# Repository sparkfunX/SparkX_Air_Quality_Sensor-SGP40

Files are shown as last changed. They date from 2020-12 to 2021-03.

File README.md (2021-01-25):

SparkX Air Quality Sensor - SGP40 (Qwiic)
========================================

SparkX SGP40 Breakout (Qwiic) (SPX-17729) (https://www.sparkfun.com/products/17729)

[*SparkX Air Quality Sensor - SGP40 (Qwiic) (SPX-17729)*](https://www.sparkfun.com/products/17729)

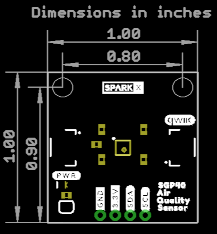
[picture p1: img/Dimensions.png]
SparkX Air Quality Sensor - SGP40


The SGP40 is a digital gas sensor designed for easy integration into air purifiers or demand-controlled ventilation systems.
Sensirion’s CMOSens® technology offers a complete, easy to use sensor system on a single chip featuring a digital
I<sup>2</sup>C interface and a temperature controlled micro hotplate, providing a humidity compensated VOC based indoor air quality signal.
The output signal can be directly processed by Sensirion’s powerful VOC Algorithm to translate the raw signal into a VOC Index as a robust
measure for indoor air quality. The VOC Algorithm automatically adapts to the environment the sensor is exposed to. Both sensing element and
VOC Algorithm feature an unmatched robustness against contaminating gases present in real world applications enabling a unique long term
stability as well as low drift and device to device variation.

Repository Contents
-------------------
* **/Documents** - datasheets etc.
* **/Hardware** - Eagle design files (.brd, .sch)

Documentation
--------------
* **[SGP40 Arduino Library](https://github.com/sparkfun/SparkFun_SGP40_Arduino_Library)** - Arduino library for the SparkFun Air Quality Sensor - SGP40.
* **[Hookup Guide]()** - Basic hookup guide for the SparkFun Air Quality Sensor - SGP40.

Product Versions
----------------
* [SPX-17729](https://www.sparkfun.com/products/17729) - Original SparkX Release.

License Information
-------------------

This product is _**open source**_!

Please review the LICENSE.md file for license information.

If you have any questions or concerns on licensing, please contact technical support on our [SparkFun forums](https://forum.sparkfun.com/viewforum.php?f=152).

Distributed as-is; no warranty is given.

- Your friends at SparkFun.

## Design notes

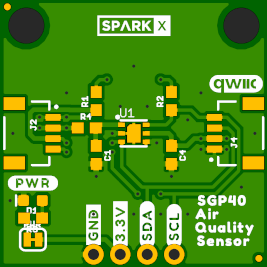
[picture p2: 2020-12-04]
img/Top.png

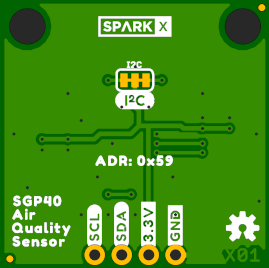
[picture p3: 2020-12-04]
img/Bottom.png

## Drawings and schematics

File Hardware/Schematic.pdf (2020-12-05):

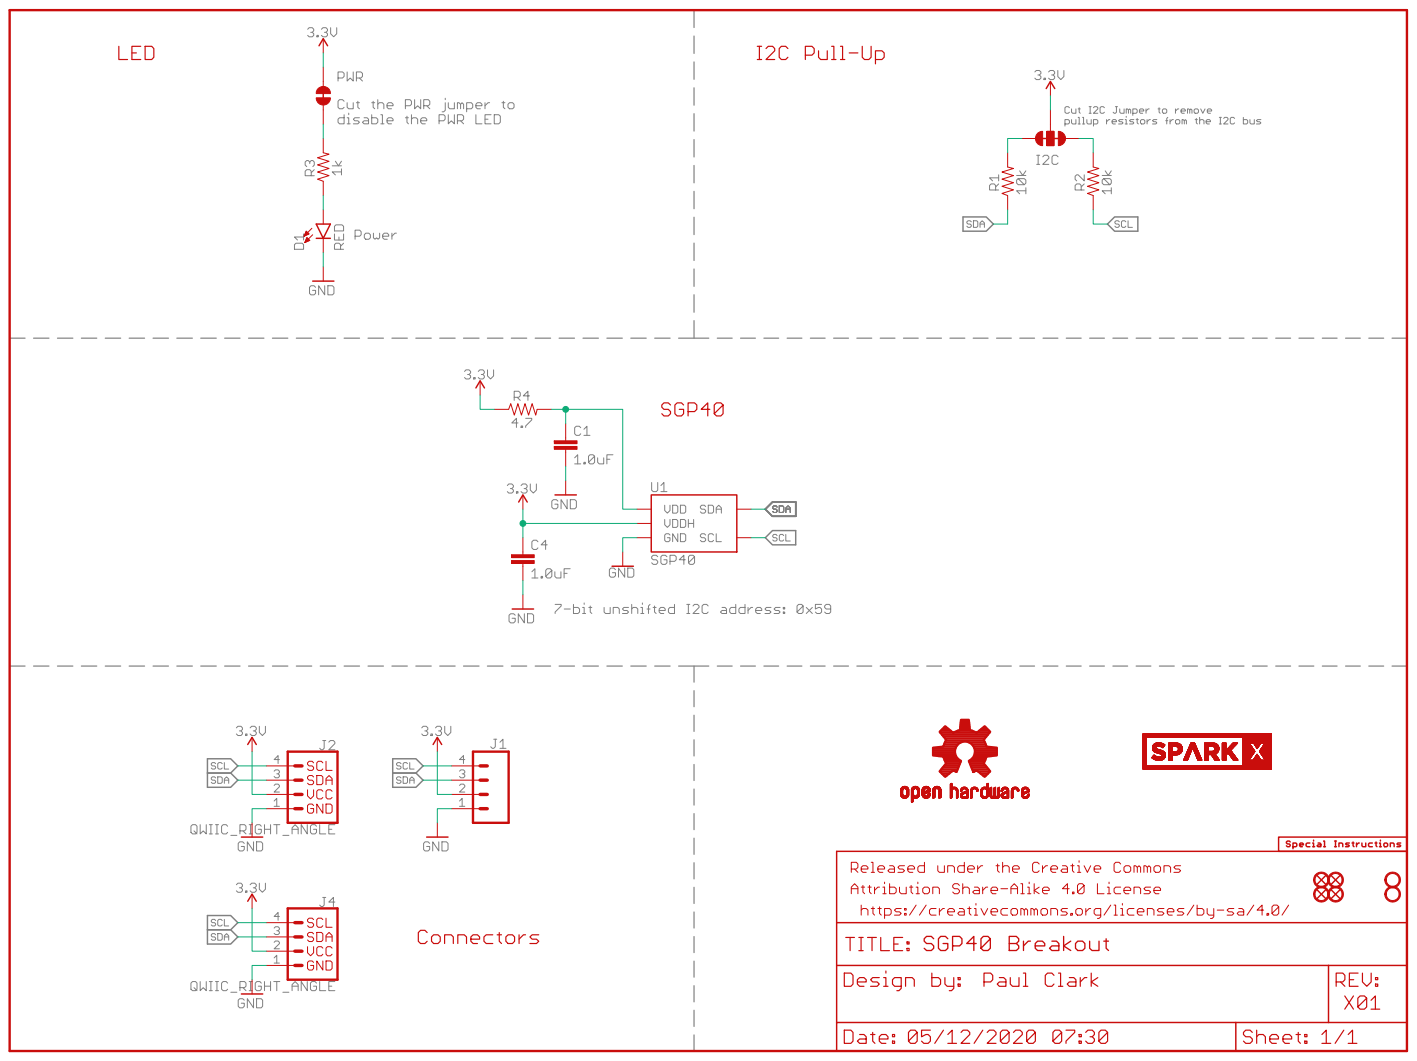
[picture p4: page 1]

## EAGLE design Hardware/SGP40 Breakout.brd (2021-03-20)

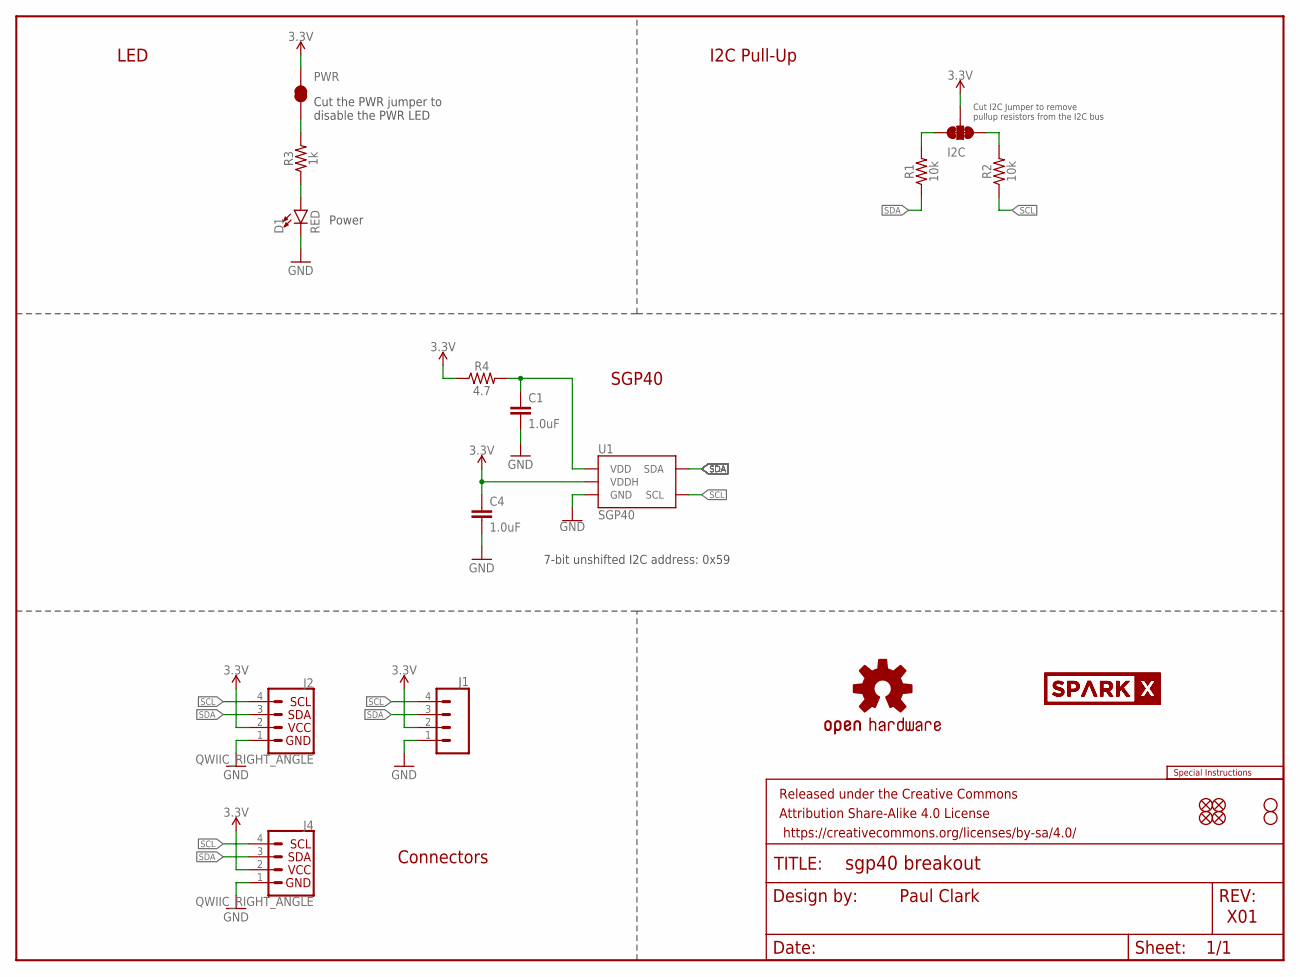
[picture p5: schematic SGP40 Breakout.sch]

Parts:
C1, C4: 1.0uF; 0603
D1: RED; LED-0603
FRAME1: FRAME-LETTER; CREATIVE_COMMONS
I2C: JUMPER-SMT_3_2-NC_TRACE_SILK; SMT-JUMPER_3_2-NC_TRACE_SILK
J1: CONN_041X04_NO_SILK; 1X04_NO_SILK
J2, J4: QWIIC_RIGHT_ANGLE; JST04_1MM_RA
JP1, JP2, JP5, JP6: FIDUCIAL1X2; FIDUCIAL-1X2
JP3, JP4: STAND-OFF
LOGO1: SPECIAL_INSTRUCTIONS-ORDERING; ORDERING_INSTRUCTIONS
LOGO5: OSHW-LOGOS; OSHW-LOGO-S
PWR: JUMPER-SMT_2_NC_TRACE_SILK; SMT-JUMPER_2_NC_TRACE_SILK
R1, R2: 10k; 0603
R3: 1k; 0603
R4: 4.7; 0603
U1: SGP40
U$10, U$18: SPARKX-LOGO3; SPARKX-SMALL

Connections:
3.3V: C4.1, I2C.2, J1.2, J2.2, J4.2, PWR.2, R4.1, U1.5 (VDDH)
GND: C1.2, C4.2, D1.C, J1.1, J2.1, J4.1, U1.2 (GND), U1.4 (GND), U1.DIEPAD (GND)
unnamed: PWR.1, R3.2
unnamed: I2C.3, R1.2
unnamed: D1.A, R3.1
unnamed: I2C.1, R2.2
unnamed: C1.1, R4.2, U1.1 (VDD)
SCL: J1.4, J2.4, J4.4, R2.1, U1.6 (SCL)
SDA: J1.3, J2.3, J4.3, R1.1, U1.3 (SDA)

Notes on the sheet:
Paul Clark
X01
7-bit unshifted I2C address: 0x59
Power
I2C Pull-Up
SGP40
Connectors
Cut the PWR jumper to disable the PWR LED
Cut I2C Jumper to remove pullup resistors from the I2C bus
LED

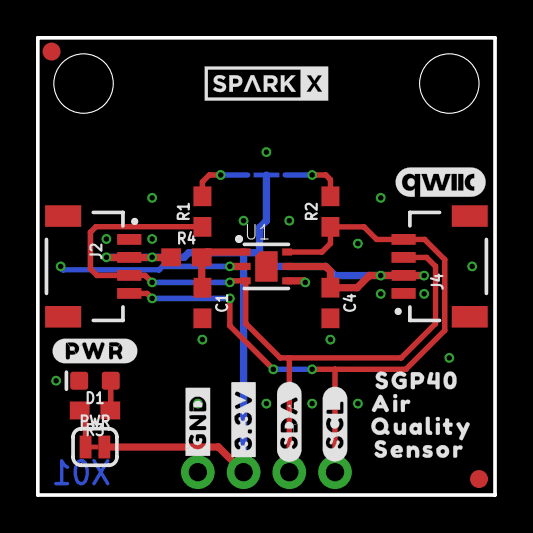
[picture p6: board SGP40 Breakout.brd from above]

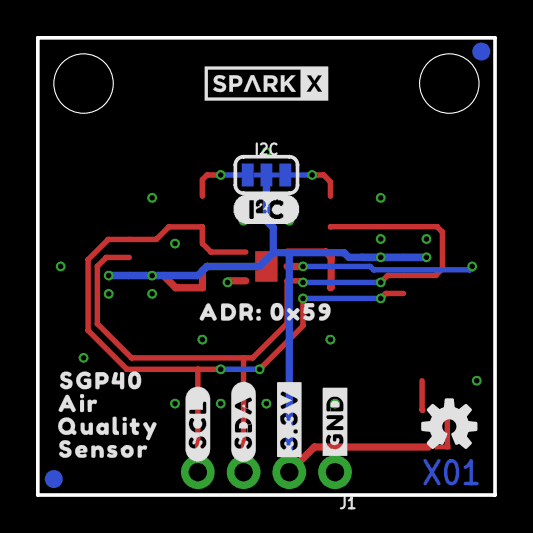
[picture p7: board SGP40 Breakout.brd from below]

Board: 2 copper layers, 25.4 x 25.4 mm, 44 parts (16 on the bottom side), 9 nets.

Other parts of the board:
U$1, U$33: #GND#0
U$2, U$34: #3#3V#0
U$3, U$35: #SDA#0
U$4, U$36: #SCL#0
U$15: I2C
U$16: QWIIC_5MM
U$19, U$20: SGP400
U$23, U$24: AIR0
U$25, U$28: QUALITY0
U$29, U$30: SENSOR0
U$31: ADR#_0X590
U$32: #PWR#0

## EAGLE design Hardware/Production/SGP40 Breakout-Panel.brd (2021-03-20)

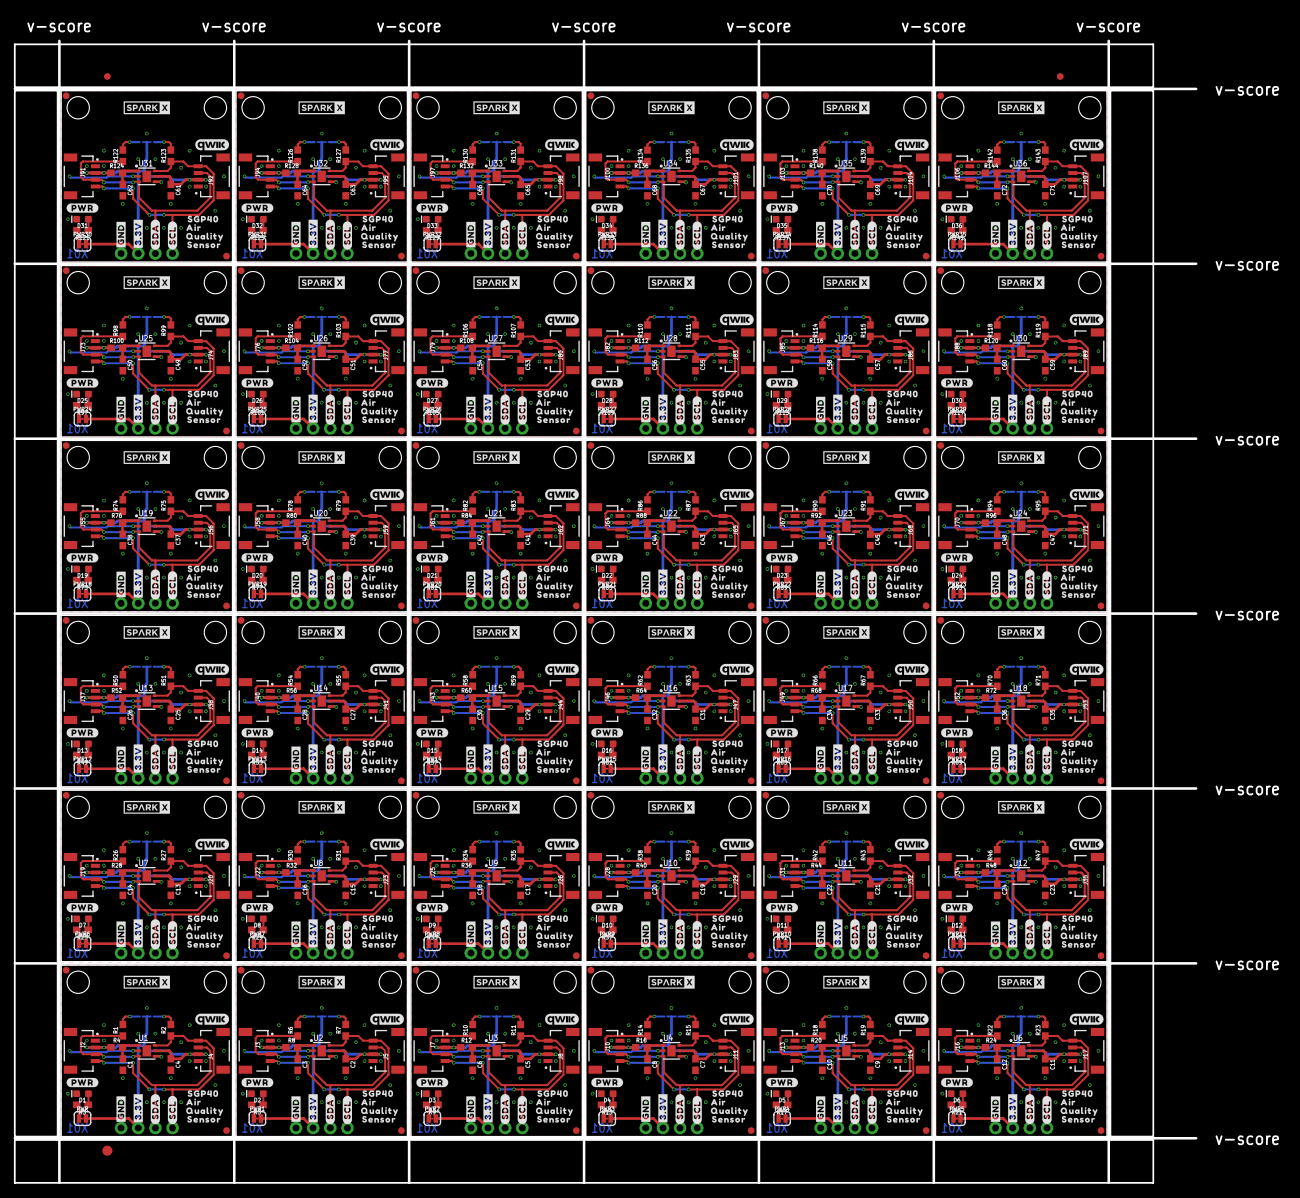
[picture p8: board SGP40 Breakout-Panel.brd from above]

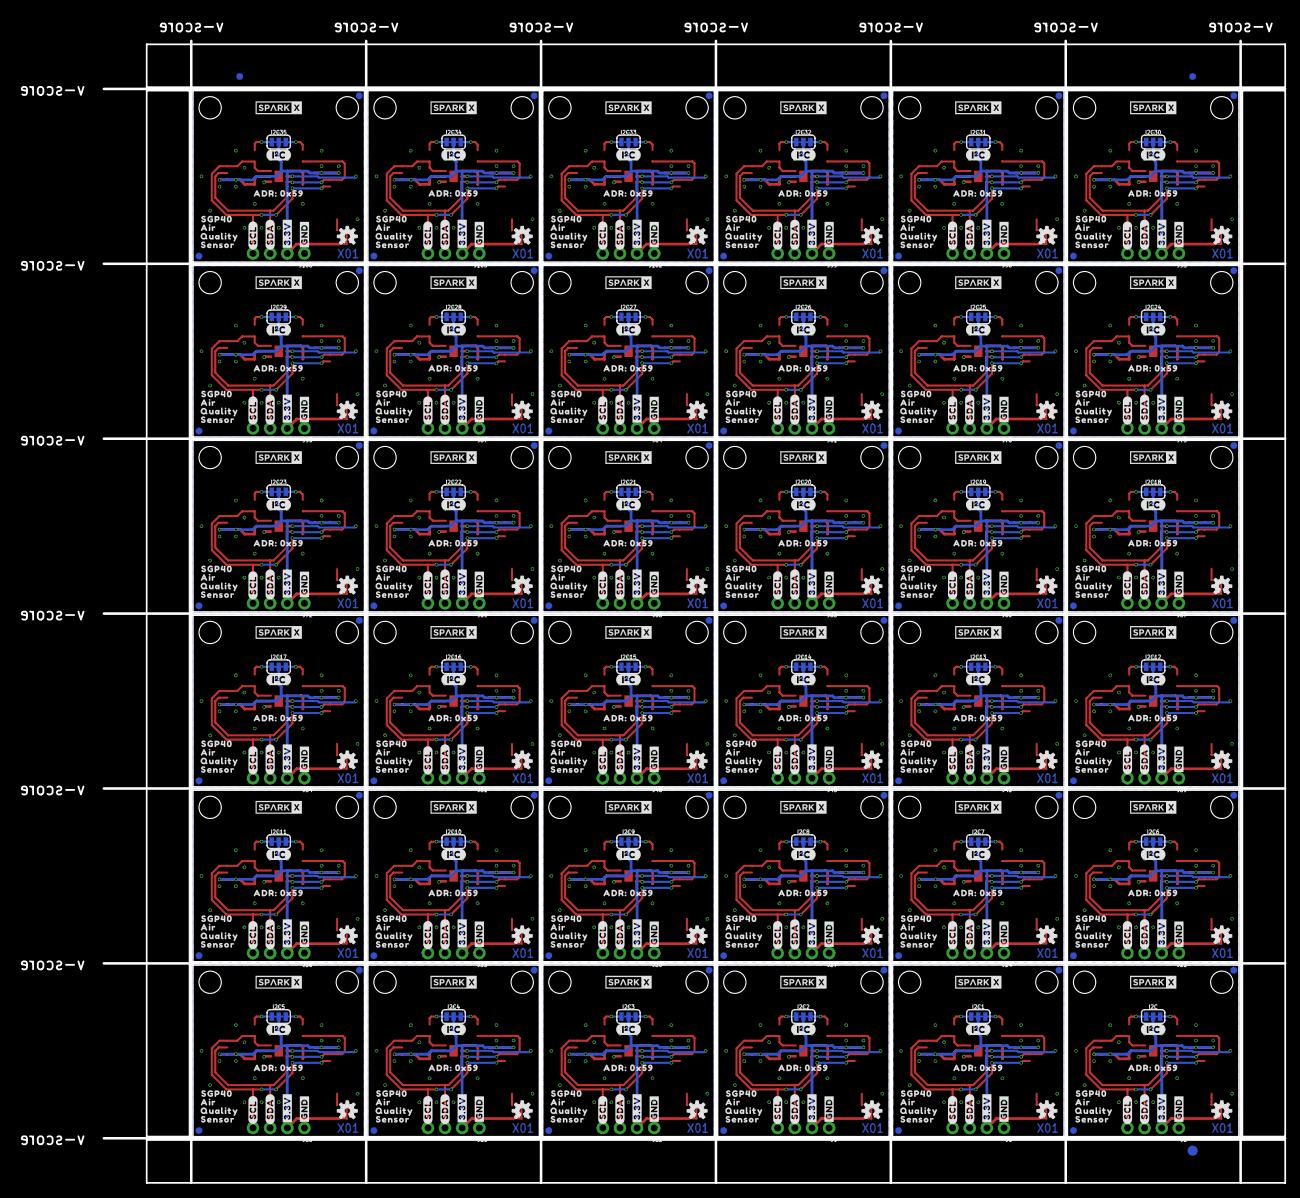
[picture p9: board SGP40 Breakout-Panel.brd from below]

Board: 2 copper layers, 175.0 x 169.2 mm, 1518 parts (579 on the bottom side), 324 nets.

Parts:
C1, C2, C3, C4, C5, C6, C7, C8, C9, C10, C11, C12, C13, C14, C15, C16, C17, C18, C19, C20, C21, C22, C23, C24, C25, C26, C27, C28, C29, C30, C31, C32, C33, C34, C35, C36, C37, C38, C39, C40, C41, C42, C43, C44, C45, C46, C47, C48, C49, C50, C51, C52, C53, C54, C55, C56, C57, C58, C59, C60, C61, C62, C63, C64, C65, C66, C67, C68, C69, C70, C71, C72: 1.0uF; 0603
D1, D2, D3, D4, D5, D6, D7, D8, D9, D10, D11, D12, D13, D14, D15, D16, D17, D18, D19, D20, D21, D22, D23, D24, D25, D26, D27, D28, D29, D30, D31, D32, D33, D34, D35, D36: RED; LED-0603
E$1, E$2, E$3, E$4: FIDUCIAL-1X2
E$5, E$6: FIDUCIAL-1.5X3
I2C, I2C1, I2C2, I2C3, I2C4, I2C5, I2C6, I2C7, I2C8, I2C9, I2C10, I2C11, I2C12, I2C13, I2C14, I2C15, I2C16, I2C17, I2C18, I2C19, I2C20, I2C21, I2C22, I2C23, I2C24, I2C25, I2C26, I2C27, I2C28, I2C29, I2C30, I2C31, I2C32, I2C33, I2C34, I2C35: JUMPER-SMT_3_2-NC_TRACE_SILK; SMT-JUMPER_3_2-NC_TRACE_SILK
J1, J6, J9, J12, J15, J18, J21, J24, J27, J30, J33, J36, J39, J42, J45, J48, J51, J54, J57, J60, J63, J66, J69, J72, J75, J78, J81, J84, J87, J90, J93, J96, J99, J102, J105, J108: 1X04_NO_SILK
J2, J3, J4, J5, J7, J8, J10, J11, J13, J14, J16, J17, J19, J20, J22, J23, J25, J26, J28, J29, J31, J32, J34, J35, J37, J38, J40, J41, J43, J44, J46, J47, J49, J50, J52, J53, J55, J56, J58, J59, J61, J62, J64, J65, J67, J68, J70, J71, J73, J74, J76, J77, J79, J80, J82, J83, J85, J86, J88, J89, J91, J92, J94, J95, J97, J98, J100, J101, J103, J104, J106, J107: QWIIC_RIGHT_ANGLE; JST04_1MM_RA
JP1, JP2, JP5, JP6, JP9, JP10, JP11, JP12, JP15, JP16, JP17, JP18, JP21, JP22, JP23, JP24, JP27, JP28, JP29, JP30, JP33, JP34, JP35, JP36, JP39, JP40, JP41, JP42, JP45, JP46, JP47, JP48, JP51, JP52, JP53, JP54, JP57, JP58, JP59, JP60, JP63, JP64, JP65, JP66, JP69, JP70, JP71, JP72, JP75, JP76, JP77, JP78, JP81, JP82, JP83, JP84, JP87, JP88, JP89, JP90, JP93, JP94, JP95, JP96, JP99, JP100, JP101, JP102, JP105, JP106, JP107, JP108, JP111, JP112, JP113, JP114, JP117, JP118, JP119, JP120, JP123, JP124, JP125, JP126, JP129, JP130, JP131, JP132, JP135, JP136, JP137, JP138, JP141, JP142, JP143, JP144, JP147, JP148, JP149, JP150, JP153, JP154, JP155, JP156, JP159, JP160, JP161, JP162, JP165, JP166, JP167, JP168, JP171, JP172, JP173, JP174, JP177, JP178, JP179, JP180, JP183, JP184, JP185, JP186, JP189, JP190, JP191, JP192, JP195, JP196, JP197, JP198, JP201, JP202, JP203, JP204, JP207, JP208, JP209, JP210, JP213, JP214, JP215, JP216: FIDUCIAL1X2; FIDUCIAL-1X2
JP3, JP4, JP7, JP8, JP13, JP14, JP19, JP20, JP25, JP26, JP31, JP32, JP37, JP38, JP43, JP44, JP49, JP50, JP55, JP56, JP61, JP62, JP67, JP68, JP73, JP74, JP79, JP80, JP85, JP86, JP91, JP92, JP97, JP98, JP103, JP104, JP109, JP110, JP115, JP116, JP121, JP122, JP127, JP128, JP133, JP134, JP139, JP140, JP145, JP146, JP151, JP152, JP157, JP158, JP163, JP164, JP169, JP170, JP175, JP176, JP181, JP182, JP187, JP188, JP193, JP194, JP199, JP200, JP205, JP206, JP211, JP212: STAND-OFF
LOGO1, LOGO2, LOGO3, LOGO4, LOGO5, LOGO6, LOGO7, LOGO8, LOGO9, LOGO10, LOGO11, LOGO12, LOGO13, LOGO14, LOGO15, LOGO16, LOGO17, LOGO18, LOGO19, LOGO20, LOGO21, LOGO22, LOGO23, LOGO24, LOGO25, LOGO26, LOGO27, LOGO28, LOGO29, LOGO30, LOGO31, LOGO32, LOGO33, LOGO34, LOGO35, LOGO36: OSHW-LOGOS; OSHW-LOGO-S
PWR, PWR1, PWR2, PWR3, PWR4, PWR5, PWR6, PWR7, PWR8, PWR9, PWR10, PWR11, PWR12, PWR13, PWR14, PWR15, PWR16, PWR17, PWR18, PWR19, PWR20, PWR21, PWR22, PWR23, PWR24, PWR25, PWR26, PWR27, PWR28, PWR29, PWR30, PWR31, PWR32, PWR33, PWR34, PWR35: JUMPER-SMT_2_NC_TRACE_SILK; SMT-JUMPER_2_NC_TRACE_SILK
R1, R2, R6, R7, R10, R11, R14, R15, R18, R19, R22, R23, R26, R27, R30, R31, R34, R35, R38, R39, R42, R43, R46, R47, R50, R51, R54, R55, R58, R59, R62, R63, R66, R67, R70, R71, R74, R75, R78, R79, R82, R83, R86, R87, R90, R91, R94, R95, R98, R99, R102, R103, R106, R107, R110, R111, R114, R115, R118, R119, R122, R123, R126, R127, R130, R131, R134, R135, R138, R139, R142, R143: 10k; 0603
R3, R5, R9, R13, R17, R21, R25, R29, R33, R37, R41, R45, R49, R53, R57, R61, R65, R69, R73, R77, R81, R85, R89, R93, R97, R101, R105, R109, R113, R117, R121, R125, R129, R133, R137, R141: 1k; 0603
R4, R8, R12, R16, R20, R24, R28, R32, R36, R40, R44, R48, R52, R56, R60, R64, R68, R72, R76, R80, R84, R88, R92, R96, R100, R104, R108, R112, R116, R120, R124, R128, R132, R136, R140, R144: 4.7; 0603
U1, U2, U3, U4, U5, U6, U7, U8, U9, U10, U11, U12, U13, U14, U15, U16, U17, U18, U19, U20, U21, U22, U23, U24, U25, U26, U27, U28, U29, U30, U31, U32, U33, U34, U35, U36: SGP40
U$1, U$33, U$37, U$41, U$59, U$63, U$81, U$85, U$103, U$107, U$125, U$129, U$147, U$151, U$169, U$173, U$191, U$195, U$213, U$217, U$235, U$239, U$257, U$261, U$279, U$283, U$301, U$305, U$323, U$327, U$345, U$349, U$367, U$371, U$389, U$393, U$411, U$415, U$433, U$437, U$455, U$459, U$477, U$481, U$499, U$503, U$521, U$525, U$543, U$547, U$565, U$569, U$587, U$591, U$609, U$613, U$631, U$635, U$653, U$657, U$675, U$679, U$697, U$701, U$719, U$723, U$741, U$745, U$763, U$767, U$785, U$789: #GND#0
U$2, U$34, U$38, U$42, U$60, U$64, U$82, U$86, U$104, U$108, U$126, U$130, U$148, U$152, U$170, U$174, U$192, U$196, U$214, U$218, U$236, U$240, U$258, U$262, U$280, U$284, U$302, U$306, U$324, U$328, U$346, U$350, U$368, U$372, U$390, U$394, U$412, U$416, U$434, U$438, U$456, U$460, U$478, U$482, U$500, U$504, U$522, U$526, U$544, U$548, U$566, U$570, U$588, U$592, U$610, U$614, U$632, U$636, U$654, U$658, U$676, U$680, U$698, U$702, U$720, U$724, U$742, U$746, U$764, U$768, U$786, U$790: #3#3V#0
U$3, U$35, U$39, U$43, U$61, U$65, U$83, U$87, U$105, U$109, U$127, U$131, U$149, U$153, U$171, U$175, U$193, U$197, U$215, U$219, U$237, U$241, U$259, U$263, U$281, U$285, U$303, U$307, U$325, U$329, U$347, U$351, U$369, U$373, U$391, U$395, U$413, U$417, U$435, U$439, U$457, U$461, U$479, U$483, U$501, U$505, U$523, U$527, U$545, U$549, U$567, U$571, U$589, U$593, U$611, U$615, U$633, U$637, U$655, U$659, U$677, U$681, U$699, U$703, U$721, U$725, U$743, U$747, U$765, U$769, U$787, U$791: #SDA#0
U$4, U$36, U$40, U$44, U$62, U$66, U$84, U$88, U$106, U$110, U$128, U$132, U$150, U$154, U$172, U$176, U$194, U$198, U$216, U$220, U$238, U$242, U$260, U$264, U$282, U$286, U$304, U$308, U$326, U$330, U$348, U$352, U$370, U$374, U$392, U$396, U$414, U$418, U$436, U$440, U$458, U$462, U$480, U$484, U$502, U$506, U$524, U$528, U$546, U$550, U$568, U$572, U$590, U$594, U$612, U$616, U$634, U$638, U$656, U$660, U$678, U$682, U$700, U$704, U$722, U$726, U$744, U$748, U$766, U$770, U$788, U$792: #SCL#0
U$5, U$15, U$45, U$67, U$89, U$111, U$133, U$155, U$177, U$199, U$221, U$243, U$265, U$287, U$309, U$331, U$353, U$375, U$397, U$419, U$441, U$463, U$485, U$507, U$529, U$551, U$573, U$595, U$617, U$639, U$661, U$683, U$705, U$727, U$749, U$771: I2C
U$6, U$16, U$46, U$68, U$90, U$112, U$134, U$156, U$178, U$200, U$222, U$244, U$266, U$288, U$310, U$332, U$354, U$376, U$398, U$420, U$442, U$464, U$486, U$508, U$530, U$552, U$574, U$596, U$618, U$640, U$662, U$684, U$706, U$728, U$750, U$772: QWIIC_5MM
U$7, U$8, U$10, U$18, U$47, U$48, U$69, U$70, U$91, U$92, U$113, U$114, U$135, U$136, U$157, U$158, U$179, U$180, U$201, U$202, U$223, U$224, U$245, U$246, U$267, U$268, U$289, U$290, U$311, U$312, U$333, U$334, U$355, U$356, U$377, U$378, U$399, U$400, U$421, U$422, U$443, U$444, U$465, U$466, U$487, U$488, U$509, U$510, U$531, U$532, U$553, U$554, U$575, U$576, U$597, U$598, U$619, U$620, U$641, U$642, U$663, U$664, U$685, U$686, U$707, U$708, U$729, U$730, U$751, U$752, U$773, U$774: SPARKX-LOGO3; SPARKX-SMALL
U$9, U$11, U$19, U$20, U$49, U$50, U$71, U$72, U$93, U$94, U$115, U$116, U$137, U$138, U$159, U$160, U$181, U$182, U$203, U$204, U$225, U$226, U$247, U$248, U$269, U$270, U$291, U$292, U$313, U$314, U$335, U$336, U$357, U$358, U$379, U$380, U$401, U$402, U$423, U$424, U$445, U$446, U$467, U$468, U$489, U$490, U$511, U$512, U$533, U$534, U$555, U$556, U$577, U$578, U$599, U$600, U$621, U$622, U$643, U$644, U$665, U$666, U$687, U$688, U$709, U$710, U$731, U$732, U$753, U$754, U$775, U$776: SGP400
U$12, U$13, U$23, U$24, U$51, U$52, U$73, U$74, U$95, U$96, U$117, U$118, U$139, U$140, U$161, U$162, U$183, U$184, U$205, U$206, U$227, U$228, U$249, U$250, U$271, U$272, U$293, U$294, U$315, U$316, U$337, U$338, U$359, U$360, U$381, U$382, U$403, U$404, U$425, U$426, U$447, U$448, U$469, U$470, U$491, U$492, U$513, U$514, U$535, U$536, U$557, U$558, U$579, U$580, U$601, U$602, U$623, U$624, U$645, U$646, U$667, U$668, U$689, U$690, U$711, U$712, U$733, U$734, U$755, U$756, U$777, U$778: AIR0
U$14, U$17, U$25, U$28, U$53, U$54, U$75, U$76, U$97, U$98, U$119, U$120, U$141, U$142, U$163, U$164, U$185, U$186, U$207, U$208, U$229, U$230, U$251, U$252, U$273, U$274, U$295, U$296, U$317, U$318, U$339, U$340, U$361, U$362, U$383, U$384, U$405, U$406, U$427, U$428, U$449, U$450, U$471, U$472, U$493, U$494, U$515, U$516, U$537, U$538, U$559, U$560, U$581, U$582, U$603, U$604, U$625, U$626, U$647, U$648, U$669, U$670, U$691, U$692, U$713, U$714, U$735, U$736, U$757, U$758, U$779, U$780: QUALITY0
U$21, U$22, U$29, U$30, U$55, U$56, U$77, U$78, U$99, U$100, U$121, U$122, U$143, U$144, U$165, U$166, U$187, U$188, U$209, U$210, U$231, U$232, U$253, U$254, U$275, U$276, U$297, U$298, U$319, U$320, U$341, U$342, U$363, U$364, U$385, U$386, U$407, U$408, U$429, U$430, U$451, U$452, U$473, U$474, U$495, U$496, U$517, U$518, U$539, U$540, U$561, U$562, U$583, U$584, U$605, U$606, U$627, U$628, U$649, U$650, U$671, U$672, U$693, U$694, U$715, U$716, U$737, U$738, U$759, U$760, U$781, U$782: SENSOR0
U$26, U$31, U$57, U$79, U$101, U$123, U$145, U$167, U$189, U$211, U$233, U$255, U$277, U$299, U$321, U$343, U$365, U$387, U$409, U$431, U$453, U$475, U$497, U$519, U$541, U$563, U$585, U$607, U$629, U$651, U$673, U$695, U$717, U$739, U$761, U$783: ADR#_0X590
U$27, U$32, U$58, U$80, U$102, U$124, U$146, U$168, U$190, U$212, U$234, U$256, U$278, U$300, U$322, U$344, U$366, U$388, U$410, U$432, U$454, U$476, U$498, U$520, U$542, U$564, U$586, U$608, U$630, U$652, U$674, U$696, U$718, U$740, U$762, U$784: #PWR#0

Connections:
3.3V: C4.1, I2C.2, J1.2, J2.2, J4.2, PWR.2, R4.1, U1.5
3.3V1: C2.1, I2C1.2, J3.2, J5.2, J6.2, PWR1.2, R8.1, U2.5
3.3V2: C5.1, I2C2.2, J7.2, J8.2, J9.2, PWR2.2, R12.1, U3.5
3.3V3: C7.1, I2C3.2, J10.2, J11.2, J12.2, PWR3.2, R16.1, U4.5
3.3V4: C9.1, I2C4.2, J13.2, J14.2, J15.2, PWR4.2, R20.1, U5.5
3.3V5: C11.1, I2C5.2, J16.2, J17.2, J18.2, PWR5.2, R24.1, U6.5
3.3V6: C13.1, I2C6.2, J19.2, J20.2, J21.2, PWR6.2, R28.1, U7.5
3.3V7: C15.1, I2C7.2, J22.2, J23.2, J24.2, PWR7.2, R32.1, U8.5
3.3V8: C17.1, I2C8.2, J25.2, J26.2, J27.2, PWR8.2, R36.1, U9.5
3.3V9: C19.1, I2C9.2, J28.2, J29.2, J30.2, PWR9.2, R40.1, U10.5
3.3V10: C21.1, I2C10.2, J31.2, J32.2, J33.2, PWR10.2, R44.1, U11.5
3.3V11: C23.1, I2C11.2, J34.2, J35.2, J36.2, PWR11.2, R48.1, U12.5
3.3V12: C25.1, I2C12.2, J37.2, J38.2, J39.2, PWR12.2, R52.1, U13.5
3.3V13: C27.1, I2C13.2, J40.2, J41.2, J42.2, PWR13.2, R56.1, U14.5
3.3V14: C29.1, I2C14.2, J43.2, J44.2, J45.2, PWR14.2, R60.1, U15.5
3.3V15: C31.1, I2C15.2, J46.2, J47.2, J48.2, PWR15.2, R64.1, U16.5
3.3V16: C33.1, I2C16.2, J49.2, J50.2, J51.2, PWR16.2, R68.1, U17.5
3.3V17: C35.1, I2C17.2, J52.2, J53.2, J54.2, PWR17.2, R72.1, U18.5
3.3V18: C37.1, I2C18.2, J55.2, J56.2, J57.2, PWR18.2, R76.1, U19.5
3.3V19: C39.1, I2C19.2, J58.2, J59.2, J60.2, PWR19.2, R80.1, U20.5
3.3V20: C41.1, I2C20.2, J61.2, J62.2, J63.2, PWR20.2, R84.1, U21.5
3.3V21: C43.1, I2C21.2, J64.2, J65.2, J66.2, PWR21.2, R88.1, U22.5
3.3V22: C45.1, I2C22.2, J67.2, J68.2, J69.2, PWR22.2, R92.1, U23.5
3.3V23: C47.1, I2C23.2, J70.2, J71.2, J72.2, PWR23.2, R96.1, U24.5
3.3V24: C49.1, I2C24.2, J73.2, J74.2, J75.2, PWR24.2, R100.1, U25.5
3.3V25: C51.1, I2C25.2, J76.2, J77.2, J78.2, PWR25.2, R104.1, U26.5
3.3V26: C53.1, I2C26.2, J79.2, J80.2, J81.2, PWR26.2, R108.1, U27.5
3.3V27: C55.1, I2C27.2, J82.2, J83.2, J84.2, PWR27.2, R112.1, U28.5
3.3V28: C57.1, I2C28.2, J85.2, J86.2, J87.2, PWR28.2, R116.1, U29.5
3.3V29: C59.1, I2C29.2, J88.2, J89.2, J90.2, PWR29.2, R120.1, U30.5
3.3V30: C61.1, I2C30.2, J91.2, J92.2, J93.2, PWR30.2, R124.1, U31.5
3.3V31: C63.1, I2C31.2, J94.2, J95.2, J96.2, PWR31.2, R128.1, U32.5
3.3V32: C65.1, I2C32.2, J97.2, J98.2, J99.2, PWR32.2, R132.1, U33.5
3.3V33: C67.1, I2C33.2, J100.2, J101.2, J102.2, PWR33.2, R136.1, U34.5
3.3V34: C69.1, I2C34.2, J103.2, J104.2, J105.2, PWR34.2, R140.1, U35.5
3.3V35: C71.1, I2C35.2, J106.2, J107.2, J108.2, PWR35.2, R144.1, U36.5
GND: C1.2, C4.2, D1.C, J1.1, J2.1, J4.1, U1.2, U1.4, U1.DIEPAD
GND1: C2.2, C3.2, D2.C, J3.1, J5.1, J6.1, U2.2, U2.4, U2.DIEPAD
GND2: C5.2, C6.2, D3.C, J7.1, J8.1, J9.1, U3.2, U3.4, U3.DIEPAD
GND3: C7.2, C8.2, D4.C, J10.1, J11.1, J12.1, U4.2, U4.4, U4.DIEPAD
GND4: C9.2, C10.2, D5.C, J13.1, J14.1, J15.1, U5.2, U5.4, U5.DIEPAD
GND5: C11.2, C12.2, D6.C, J16.1, J17.1, J18.1, U6.2, U6.4, U6.DIEPAD
GND6: C13.2, C14.2, D7.C, J19.1, J20.1, J21.1, U7.2, U7.4, U7.DIEPAD
GND7: C15.2, C16.2, D8.C, J22.1, J23.1, J24.1, U8.2, U8.4, U8.DIEPAD
GND8: C17.2, C18.2, D9.C, J25.1, J26.1, J27.1, U9.2, U9.4, U9.DIEPAD
GND9: C19.2, C20.2, D10.C, J28.1, J29.1, J30.1, U10.2, U10.4, U10.DIEPAD
GND10: C21.2, C22.2, D11.C, J31.1, J32.1, J33.1, U11.2, U11.4, U11.DIEPAD
GND11: C23.2, C24.2, D12.C, J34.1, J35.1, J36.1, U12.2, U12.4, U12.DIEPAD
GND12: C25.2, C26.2, D13.C, J37.1, J38.1, J39.1, U13.2, U13.4, U13.DIEPAD
GND13: C27.2, C28.2, D14.C, J40.1, J41.1, J42.1, U14.2, U14.4, U14.DIEPAD
GND14: C29.2, C30.2, D15.C, J43.1, J44.1, J45.1, U15.2, U15.4, U15.DIEPAD
GND15: C31.2, C32.2, D16.C, J46.1, J47.1, J48.1, U16.2, U16.4, U16.DIEPAD
GND16: C33.2, C34.2, D17.C, J49.1, J50.1, J51.1, U17.2, U17.4, U17.DIEPAD
GND17: C35.2, C36.2, D18.C, J52.1, J53.1, J54.1, U18.2, U18.4, U18.DIEPAD
GND18: C37.2, C38.2, D19.C, J55.1, J56.1, J57.1, U19.2, U19.4, U19.DIEPAD
GND19: C39.2, C40.2, D20.C, J58.1, J59.1, J60.1, U20.2, U20.4, U20.DIEPAD
GND20: C41.2, C42.2, D21.C, J61.1, J62.1, J63.1, U21.2, U21.4, U21.DIEPAD
GND21: C43.2, C44.2, D22.C, J64.1, J65.1, J66.1, U22.2, U22.4, U22.DIEPAD
GND22: C45.2, C46.2, D23.C, J67.1, J68.1, J69.1, U23.2, U23.4, U23.DIEPAD
GND23: C47.2, C48.2, D24.C, J70.1, J71.1, J72.1, U24.2, U24.4, U24.DIEPAD
GND24: C49.2, C50.2, D25.C, J73.1, J74.1, J75.1, U25.2, U25.4, U25.DIEPAD
GND25: C51.2, C52.2, D26.C, J76.1, J77.1, J78.1, U26.2, U26.4, U26.DIEPAD
GND26: C53.2, C54.2, D27.C, J79.1, J80.1, J81.1, U27.2, U27.4, U27.DIEPAD
GND27: C55.2, C56.2, D28.C, J82.1, J83.1, J84.1, U28.2, U28.4, U28.DIEPAD
GND28: C57.2, C58.2, D29.C, J85.1, J86.1, J87.1, U29.2, U29.4, U29.DIEPAD
GND29: C59.2, C60.2, D30.C, J88.1, J89.1, J90.1, U30.2, U30.4, U30.DIEPAD
GND30: C61.2, C62.2, D31.C, J91.1, J92.1, J93.1, U31.2, U31.4, U31.DIEPAD
GND31: C63.2, C64.2, D32.C, J94.1, J95.1, J96.1, U32.2, U32.4, U32.DIEPAD
GND32: C65.2, C66.2, D33.C, J97.1, J98.1, J99.1, U33.2, U33.4, U33.DIEPAD
GND33: C67.2, C68.2, D34.C, J100.1, J101.1, J102.1, U34.2, U34.4, U34.DIEPAD
GND34: C69.2, C70.2, D35.C, J103.1, J104.1, J105.1, U35.2, U35.4, U35.DIEPAD
GND35: C71.2, C72.2, D36.C, J106.1, J107.1, J108.1, U36.2, U36.4, U36.DIEPAD
unnamed: PWR.1, R3.2
unnamed: I2C.3, R1.2
unnamed: D1.A, R3.1
unnamed: I2C.1, R2.2
unnamed: C1.1, R4.2, U1.1
unnamed: D2.A, R5.1
unnamed: PWR1.1, R5.2
unnamed: I2C1.3, R6.2
unnamed: I2C1.1, R7.2
unnamed: C3.1, R8.2, U2.1
unnamed: D3.A, R9.1
unnamed: PWR2.1, R9.2
unnamed: I2C2.3, R10.2
unnamed: I2C2.1, R11.2
unnamed: C6.1, R12.2, U3.1
unnamed: D4.A, R13.1
unnamed: PWR3.1, R13.2
unnamed: I2C3.3, R14.2
unnamed: I2C3.1, R15.2
unnamed: C8.1, R16.2, U4.1
unnamed: D5.A, R17.1
unnamed: PWR4.1, R17.2
unnamed: I2C4.3, R18.2
unnamed: I2C4.1, R19.2
unnamed: C10.1, R20.2, U5.1
unnamed: D6.A, R21.1
unnamed: PWR5.1, R21.2
unnamed: I2C5.3, R22.2
unnamed: I2C5.1, R23.2
unnamed: C12.1, R24.2, U6.1
unnamed: D7.A, R25.1
unnamed: PWR6.1, R25.2
unnamed: I2C6.3, R26.2
unnamed: I2C6.1, R27.2
unnamed: C14.1, R28.2, U7.1
unnamed: D8.A, R29.1
unnamed: PWR7.1, R29.2
unnamed: I2C7.3, R30.2
unnamed: I2C7.1, R31.2
unnamed: C16.1, R32.2, U8.1
unnamed: D9.A, R33.1
unnamed: PWR8.1, R33.2
unnamed: I2C8.3, R34.2
unnamed: I2C8.1, R35.2
unnamed: C18.1, R36.2, U9.1
unnamed: D10.A, R37.1
unnamed: PWR9.1, R37.2
unnamed: I2C9.3, R38.2
unnamed: I2C9.1, R39.2
unnamed: C20.1, R40.2, U10.1
unnamed: D11.A, R41.1
unnamed: PWR10.1, R41.2
unnamed: I2C10.3, R42.2
unnamed: I2C10.1, R43.2
unnamed: C22.1, R44.2, U11.1
unnamed: D12.A, R45.1
unnamed: PWR11.1, R45.2
unnamed: I2C11.3, R46.2
unnamed: I2C11.1, R47.2
unnamed: C24.1, R48.2, U12.1
unnamed: D13.A, R49.1
unnamed: PWR12.1, R49.2
unnamed: I2C12.3, R50.2
unnamed: I2C12.1, R51.2
unnamed: C26.1, R52.2, U13.1
unnamed: D14.A, R53.1
unnamed: PWR13.1, R53.2
unnamed: I2C13.3, R54.2
unnamed: I2C13.1, R55.2
unnamed: C28.1, R56.2, U14.1
unnamed: D15.A, R57.1
unnamed: PWR14.1, R57.2
unnamed: I2C14.3, R58.2
unnamed: I2C14.1, R59.2
unnamed: C30.1, R60.2, U15.1
unnamed: D16.A, R61.1
unnamed: PWR15.1, R61.2
unnamed: I2C15.3, R62.2
unnamed: I2C15.1, R63.2
unnamed: C32.1, R64.2, U16.1
unnamed: D17.A, R65.1
unnamed: PWR16.1, R65.2
unnamed: I2C16.3, R66.2
unnamed: I2C16.1, R67.2
unnamed: C34.1, R68.2, U17.1
unnamed: D18.A, R69.1
unnamed: PWR17.1, R69.2
unnamed: I2C17.3, R70.2
unnamed: I2C17.1, R71.2
unnamed: C36.1, R72.2, U18.1
unnamed: D19.A, R73.1
unnamed: PWR18.1, R73.2
unnamed: I2C18.3, R74.2
unnamed: I2C18.1, R75.2
unnamed: C38.1, R76.2, U19.1
unnamed: D20.A, R77.1
unnamed: PWR19.1, R77.2
unnamed: I2C19.3, R78.2
unnamed: I2C19.1, R79.2
unnamed: C40.1, R80.2, U20.1
unnamed: D21.A, R81.1
unnamed: PWR20.1, R81.2
unnamed: I2C20.3, R82.2
unnamed: I2C20.1, R83.2
unnamed: C42.1, R84.2, U21.1
unnamed: D22.A, R85.1
unnamed: PWR21.1, R85.2
unnamed: I2C21.3, R86.2
unnamed: I2C21.1, R87.2
unnamed: C44.1, R88.2, U22.1
unnamed: D23.A, R89.1
unnamed: PWR22.1, R89.2
unnamed: I2C22.3, R90.2
unnamed: I2C22.1, R91.2
unnamed: C46.1, R92.2, U23.1
unnamed: D24.A, R93.1
unnamed: PWR23.1, R93.2
unnamed: I2C23.3, R94.2
unnamed: I2C23.1, R95.2
unnamed: C48.1, R96.2, U24.1
unnamed: D25.A, R97.1
unnamed: PWR24.1, R97.2
unnamed: I2C24.3, R98.2
unnamed: I2C24.1, R99.2
unnamed: C50.1, R100.2, U25.1
unnamed: D26.A, R101.1
unnamed: PWR25.1, R101.2
unnamed: I2C25.3, R102.2
unnamed: I2C25.1, R103.2
unnamed: C52.1, R104.2, U26.1
unnamed: D27.A, R105.1
unnamed: PWR26.1, R105.2
unnamed: I2C26.3, R106.2
unnamed: I2C26.1, R107.2
unnamed: C54.1, R108.2, U27.1
unnamed: D28.A, R109.1
unnamed: PWR27.1, R109.2
unnamed: I2C27.3, R110.2
unnamed: I2C27.1, R111.2
unnamed: C56.1, R112.2, U28.1
unnamed: D29.A, R113.1
unnamed: PWR28.1, R113.2
unnamed: I2C28.3, R114.2
unnamed: I2C28.1, R115.2
unnamed: C58.1, R116.2, U29.1
unnamed: D30.A, R117.1
unnamed: PWR29.1, R117.2
unnamed: I2C29.3, R118.2
unnamed: I2C29.1, R119.2
unnamed: C60.1, R120.2, U30.1
unnamed: D31.A, R121.1
unnamed: PWR30.1, R121.2
unnamed: I2C30.3, R122.2
unnamed: I2C30.1, R123.2
unnamed: C62.1, R124.2, U31.1
unnamed: D32.A, R125.1
unnamed: PWR31.1, R125.2
unnamed: I2C31.3, R126.2
unnamed: I2C31.1, R127.2
unnamed: C64.1, R128.2, U32.1
unnamed: D33.A, R129.1
unnamed: PWR32.1, R129.2
unnamed: I2C32.3, R130.2
unnamed: I2C32.1, R131.2
unnamed: C66.1, R132.2, U33.1
unnamed: D34.A, R133.1
unnamed: PWR33.1, R133.2
unnamed: I2C33.3, R134.2
unnamed: I2C33.1, R135.2
unnamed: C68.1, R136.2, U34.1
unnamed: D35.A, R137.1
unnamed: PWR34.1, R137.2
unnamed: I2C34.3, R138.2
unnamed: I2C34.1, R139.2
unnamed: C70.1, R140.2, U35.1
unnamed: D36.A, R141.1
unnamed: PWR35.1, R141.2
unnamed: I2C35.3, R142.2
unnamed: I2C35.1, R143.2
unnamed: C72.1, R144.2, U36.1
SCL: J1.4, J2.4, J4.4, R2.1, U1.6
SCL1: J3.4, J5.4, J6.4, R7.1, U2.6
SCL2: J7.4, J8.4, J9.4, R11.1, U3.6
SCL3: J10.4, J11.4, J12.4, R15.1, U4.6
SCL4: J13.4, J14.4, J15.4, R19.1, U5.6
SCL5: J16.4, J17.4, J18.4, R23.1, U6.6
SCL6: J19.4, J20.4, J21.4, R27.1, U7.6
SCL7: J22.4, J23.4, J24.4, R31.1, U8.6
SCL8: J25.4, J26.4, J27.4, R35.1, U9.6
SCL9: J28.4, J29.4, J30.4, R39.1, U10.6
SCL10: J31.4, J32.4, J33.4, R43.1, U11.6
SCL11: J34.4, J35.4, J36.4, R47.1, U12.6
SCL12: J37.4, J38.4, J39.4, R51.1, U13.6
SCL13: J40.4, J41.4, J42.4, R55.1, U14.6
SCL14: J43.4, J44.4, J45.4, R59.1, U15.6
SCL15: J46.4, J47.4, J48.4, R63.1, U16.6
SCL16: J49.4, J50.4, J51.4, R67.1, U17.6
SCL17: J52.4, J53.4, J54.4, R71.1, U18.6
SCL18: J55.4, J56.4, J57.4, R75.1, U19.6
SCL19: J58.4, J59.4, J60.4, R79.1, U20.6
SCL20: J61.4, J62.4, J63.4, R83.1, U21.6
SCL21: J64.4, J65.4, J66.4, R87.1, U22.6
SCL22: J67.4, J68.4, J69.4, R91.1, U23.6
SCL23: J70.4, J71.4, J72.4, R95.1, U24.6
SCL24: J73.4, J74.4, J75.4, R99.1, U25.6
SCL25: J76.4, J77.4, J78.4, R103.1, U26.6
SCL26: J79.4, J80.4, J81.4, R107.1, U27.6
SCL27: J82.4, J83.4, J84.4, R111.1, U28.6
SCL28: J85.4, J86.4, J87.4, R115.1, U29.6
SCL29: J88.4, J89.4, J90.4, R119.1, U30.6
SCL30: J91.4, J92.4, J93.4, R123.1, U31.6
SCL31: J94.4, J95.4, J96.4, R127.1, U32.6
SCL32: J97.4, J98.4, J99.4, R131.1, U33.6
SCL33: J100.4, J101.4, J102.4, R135.1, U34.6
SCL34: J103.4, J104.4, J105.4, R139.1, U35.6
SCL35: J106.4, J107.4, J108.4, R143.1, U36.6
SDA: J1.3, J2.3, J4.3, R1.1, U1.3
SDA1: J3.3, J5.3, J6.3, R6.1, U2.3
SDA2: J7.3, J8.3, J9.3, R10.1, U3.3
SDA3: J10.3, J11.3, J12.3, R14.1, U4.3
SDA4: J13.3, J14.3, J15.3, R18.1, U5.3
SDA5: J16.3, J17.3, J18.3, R22.1, U6.3
SDA6: J19.3, J20.3, J21.3, R26.1, U7.3
SDA7: J22.3, J23.3, J24.3, R30.1, U8.3
SDA8: J25.3, J26.3, J27.3, R34.1, U9.3
SDA9: J28.3, J29.3, J30.3, R38.1, U10.3
SDA10: J31.3, J32.3, J33.3, R42.1, U11.3
SDA11: J34.3, J35.3, J36.3, R46.1, U12.3
SDA12: J37.3, J38.3, J39.3, R50.1, U13.3
SDA13: J40.3, J41.3, J42.3, R54.1, U14.3
SDA14: J43.3, J44.3, J45.3, R58.1, U15.3
SDA15: J46.3, J47.3, J48.3, R62.1, U16.3
SDA16: J49.3, J50.3, J51.3, R66.1, U17.3
SDA17: J52.3, J53.3, J54.3, R70.1, U18.3
SDA18: J55.3, J56.3, J57.3, R74.1, U19.3
SDA19: J58.3, J59.3, J60.3, R78.1, U20.3
SDA20: J61.3, J62.3, J63.3, R82.1, U21.3
SDA21: J64.3, J65.3, J66.3, R86.1, U22.3
SDA22: J67.3, J68.3, J69.3, R90.1, U23.3
SDA23: J70.3, J71.3, J72.3, R94.1, U24.3
SDA24: J73.3, J74.3, J75.3, R98.1, U25.3
SDA25: J76.3, J77.3, J78.3, R102.1, U26.3
SDA26: J79.3, J80.3, J81.3, R106.1, U27.3
SDA27: J82.3, J83.3, J84.3, R110.1, U28.3
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

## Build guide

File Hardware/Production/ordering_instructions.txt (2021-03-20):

panel size, 169x169mm
PCB thickness, 1.6mm
number of layers, 2
soldermask color, Black
silkscreen color, White
oz copper, 1oz
finish, HASL lead free
stencils, top
pcs per panel, 36
min trace width, 0.3048mm / 0.0120in
min drill size, 0.3000mm / 0.0118in

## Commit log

2020-12-04 Adding X01 PCB and images
    [SGP40 Breakout-Panel.GBL, SGP40 Breakout-Panel.GBO, SGP40 Breakout-Panel.GBP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]
2020-12-05 Adding the missing PROD_IDs. Moved schematic block titles to the Symbol layer.
    [SGP40 Breakout.brd, SGP40 Breakout.sch]
2021-03-20 Remove New-Parts. Tweak 0.3mm drill size.
    [SGP40 Breakout-Panel.brd, SGP40 Breakout.brd, SGP40 Breakout.sch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]

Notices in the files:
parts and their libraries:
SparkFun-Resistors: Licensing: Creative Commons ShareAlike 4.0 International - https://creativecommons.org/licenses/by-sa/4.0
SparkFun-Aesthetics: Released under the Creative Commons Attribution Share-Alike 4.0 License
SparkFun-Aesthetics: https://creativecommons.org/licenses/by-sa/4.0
